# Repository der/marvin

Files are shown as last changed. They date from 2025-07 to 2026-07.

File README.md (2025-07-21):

# Marvin

Project to built a mobile, sensing, semi-intelligent robot.

## Goal capabilities

- can drive from a joystick
- can drive itself from base AI model, including explore for itself
- proximity sensing and never crashes into things
- audio input
	- directional audio to allow turn to sound?
- audio output
- vision for scene understanding and face recognition
- some emoting - know when it hears you or recognises you, when thinking or exploring
- modular system so could change to biped or add manipulators in the future

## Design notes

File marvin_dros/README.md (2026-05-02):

# Controller and sensor nodes for Marvin

Originally used ROS2 over rosbridge.

Ditched ROS2 as too unstable, and moved to simple websocket based pub/sub mechanism.

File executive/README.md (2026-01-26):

# Marvin Executive System

An intelligent rover control system that uses LLM-based agents for high-level planning and decision-making.

## Overview

This system controls a mobile rover with mecanum wheels, camera, and sensors through a two-layer architecture:

- **Executive Agent**: High-level planning and decision-making using an LLM (via pydantic-ai)
- **Cortex**: Low-level control, state monitoring, and obstacle detection

## Components

### State Models (`state.py`)
Defines shared state structures:
- `RoverState`: Low-level rover status (heading, movement, obstacles, visible objects)
- `HighLevelState`: Executive-level state (mode, goals, plans)

### Cortex (`cortex.py`)
Low-level rover control:
- Monitors sensors every 200ms
- Executes movement plans
- Stops automatically when obstacles are < 10cm away
- Uses dummy interface (replace with actual camera_server API later)

### Executive Agent (`executive.py`)
LLM-powered decision-making with tools:
- `check_object_visible`: Check if named object is in view
- `turn_to_object`: Rotate to face a visible object
- `move_direction`: Move forward/backward for a distance
- `get_current_heading`: Query current compass heading
- `get_obstacle_distance`: Check distance to nearest obstacle
- `update_goal`: Set new high-level goal

### Dialog Handler (`dialog.py`)
User interaction interface:
- Processes text commands from terminal
- Special commands: `stop`, `status`, `quit`/`exit`
- Coordinates between executive and cortex

## Setup

1. Install dependencies:
```bash
pip install -r requirements.txt
```

2. Make sure you have an LLM running with OpenAI-compatible API (e.g., llama.cpp server):
```bash
# Example: llama.cpp server on port 8080
./server -m model.gguf --port 8080
```

## Usage

Run the system:
```bash
python main.py
```

With custom LLM settings:
```bash
python main.py --model-url http://localhost:8080/v1 --model-name my-model
```

### Commands

- Type natural language instructions (e.g., "turn left", "find the teddy bear")
- `stop` - Emergency stop the rover
- `status` - Show current system state
- `quit` or `exit` - Shutdown

### Example Tasks

From the design outline:
- "there's a teddy bear to your left, go up to it"
- "turn around and tell me what objects you see"
- "go up to the waste basket"
- "can you see a book? what is it called?"
- "explore this room and find a book and a bear"

## Current Implementation Status

✅ Core framework with state management
✅ Executive agent with pydantic-ai and tool definitions
✅ Cortex with dummy rover interface
✅ Dialog handler for user interaction
✅ Asynchronous control loops

🔄 Using dummy data for:
- Rover movement (simulated)
- Object detection (random dummy objects)
- Obstacle distance (simulated)

## Future Enhancements

1. **Replace dummy interface**: Connect to actual `../pi-master/camera_server.py`
2. **Vision integration**: Add real object detection using VLM
3. **Better planning**: More sophisticated movement sequences
4. **Odometry**: Track actual distance traveled
5. **Vision-language model**: Integrate VLM for visual understanding
6. **Persistent memory**: Save and recall previous interactions

## Architecture

```
┌─────────────┐
│   User      │
│   Input     │
└──────┬──────┘
       │
┌──────▼──────────┐
│  Dialog Handler │
└──────┬──────────┘
       │
┌──────▼────────────┐      ┌─────────────┐
│ Executive Agent   │◄─────┤  LLM API    │
│  (High Level)     │      │  (OpenAI)   │
└──────┬────────────┘      └─────────────┘
       │
       │ Plans/Commands
       │
┌──────▼──────────┐       ┌──────────────┐
│     Cortex      │◄──────┤  Rover API   │
│  (Low Level)    │       │ camera_server│
└─────────────────┘       └──────────────┘
       │
       │ Motor Control
       │
┌──────▼──────────┐
│  Physical Rover │
│  Sensors/Camera │
└─────────────────┘
```

## Notes

- The system runs two async loops: cortex control and dialog handling
- State updates happen every 200ms by default (configurable)
- Obstacle detection triggers automatic stops
- The framework is designed to be extended with real hardware interfaces

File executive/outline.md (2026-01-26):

# Outline of executive and cortex structure

## Background

This will the controller for a small mobile droid interacting with a domestic environment. The physical capabilities of the droid will evolve over time. Currently it comprises:

- a mobile rover platform with mercanum wheels above to move forward/back, rotate on the spot but also slide sideways or diagonally
- a camera able to deliver video or still capture at low or HD resolution
- sensors for absolute heading and distance to obstacles in front (and at 30 degrees either side of the front)
- an onboard Raspberry Pi running a web server that can be used to obtain camera and sensor data and to send movement instructions

The web server code is in ../pi-master/camera_server.py

## Goal for this development

Build an agent layer (the "executive") that takes prompts form the user (initially typed into the terminal) and maps out a plan for what the rover should do.

Build a lower layer (the "cortex") which executes the plan but monitors if the rover is getting too close to an obstacle or if the plan is complete. In such cases it should stop the rover and ask the executive what to do next.

The LLMs used by the executive will be running locally in llama.cpp in this machine, the details of that are out of scope here.

There will be a thinking model on one localhost port and a VLM model on another port.

## Example test tasks

- there's a teddy bear to your left, go up to it
- turn around and tell me what objects you see
- go up to the waste basket
- can you see a book?
  what is it called?
- explore this room and find a book and a bear

## Initial outline

### Dialog handler

- A module that takes text input from the terminal.
- If the text is "stop" it tells the context the stop the rover.
- Otherwise it should pass the prompt the exective along with a summary of the current state so that the executive can decide whether to change the plan or simply repond to the prompt without changing the plan.
- Outputs from the executive agent should be shown back the user

### An Executive Agent

- This should use an LLM on a localhost port (with OpenAI compatible completions API).
- It should be implemented using the pydantic.ai framework
- It should take current state, event updates from the cortext and prompts from the user and either:
   - send a text response to the user without further need for tool use
   - use tool calls to help answer the question but without changing the plan
   - update the plan the cortext should be following

### A cortex module

- This should maintain a state object for the current plan and drive the rover via the camera_server web interface to execute the plan
- Check if there an obstacle closer than 10cm and if so stop the rover and inform the executive
- Provide a call that the dialog handler can invoke directly if the users says "stop"
- the cortex should update the rover state information (see below) once every 200ms

### State

The modules should coordinate via two groups of state information.

#### High level state

- rover mode (standby, acting)
- current goal as set by the user prompts
- high level plan for how to achieve this generated by the executive LLM

#### Rover state

- heading
- isMoving
- distanceToObstacle
- current camera image
- list of visible objects and their heading

### Tools to provide to the executive

- check if an object of named time is visible
- turn to the object, if is visible
- move in a direction for a distance
- a sequence of movment actions
- get the current heading
- return the distance to obstacle in front

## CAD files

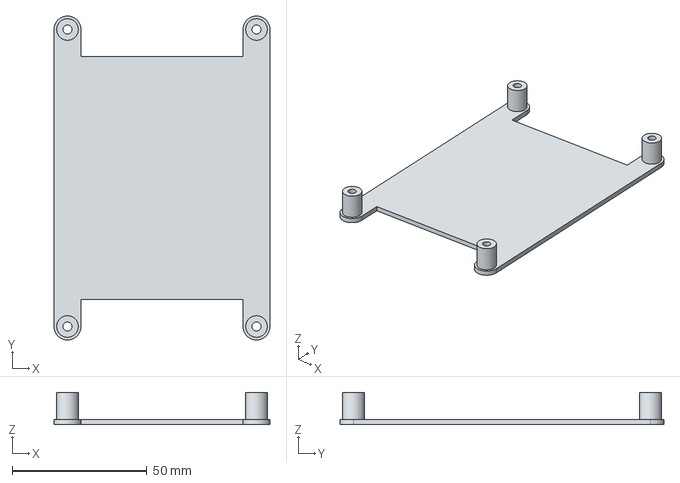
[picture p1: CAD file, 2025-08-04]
motor-base/cad/Underplate.step
80.0 x 120.0 x 12.0 mm

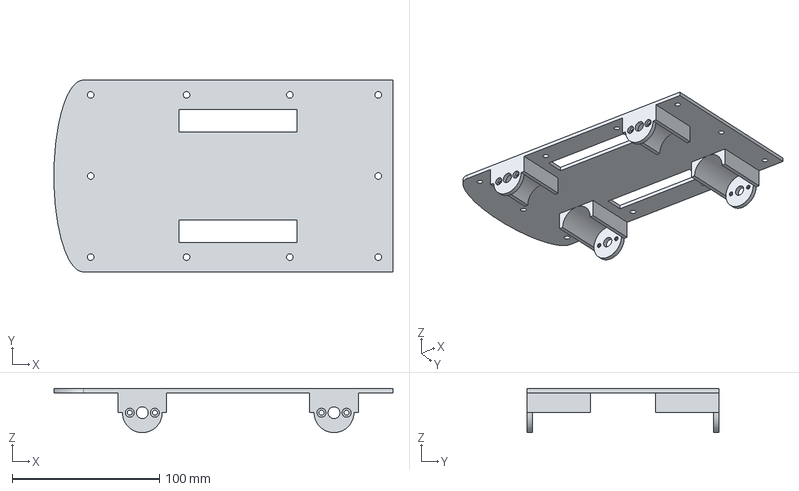
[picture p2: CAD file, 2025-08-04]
motor-base/cad/Base.step
229.9 x 130.0 x 30.0 mm

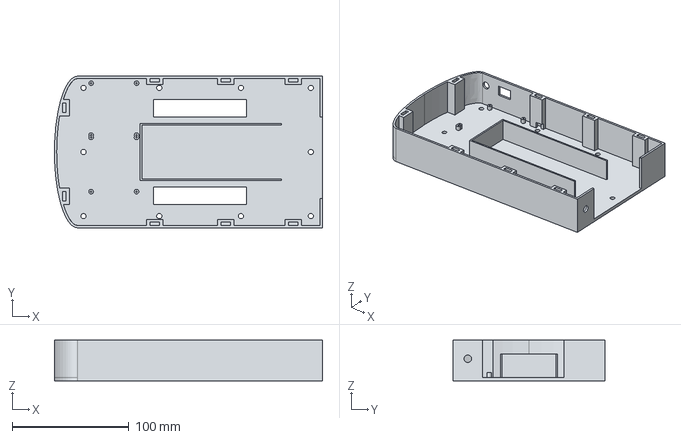
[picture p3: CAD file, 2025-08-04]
motor-base/cad/PowerLayer.step
229.9 x 130.0 x 35.0 mm

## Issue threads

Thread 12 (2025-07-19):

Design and print prototyping base

der, 2025-07-19:
- supports for fixing to mobile base
- pi fixing
- camera fixing
- space for front lidar or us
- elevated platform for full lidar
- hole for power cable
-

Closed 2025-10-04.

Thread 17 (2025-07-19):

Test wifi stability with motion

der, 2025-07-19:

der, 2025-08-22:
Not great even with second dongle acting as an AP.

Getting dropouts, and long drop outs of round corner from controller, might be partly controller wifi pickup but.

der, 2025-08-22:
Dropped use of AP so pi can use either builtin or dongle wifi to reach house network, noticeably more stable.

Closed 2025-08-22.

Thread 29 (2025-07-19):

Audio output on pi

der, 2025-07-19:

der, 2025-08-24:
USB audio speaker works but a little quiet out of the box.

To discover the device use `pw-cli ls Node`, fine the node that mentions output or stereo and get its id. For Marvin it seems to be 87.
```
	id 87, type PipeWire:Interface:Node/3
 		object.serial = "88"
 		object.path = "alsa:acp:UACDemoV10:1:playback"
 		factory.id = "19"
 		client.id = "36"
 		device.id = "68"
 		priority.session = "1009"
 		priority.driver = "1009"
 		node.description = "UACDemoV1.0 Analog Stereo"
 		node.name = "alsa_output.usb-Jieli_Technology_UACDemoV1.0_4150344133363815-00.analog-stereo"
 		node.nick = "UACDemoV1.0"
 		media.class = "Audio/Sink"
```
Then can set the volume with e.g.:
```
pw-cli s 87 Props '{channelVolumes:[2.0,2.0]}'
```
Tested this by apt installing espeak and using that to get test speech output.

Closed 2025-08-24.

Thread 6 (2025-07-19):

Design and print base plate for motors

der, 2025-07-19:
- motor brackets
- holes for motor cables
- circuit board fixing holes
- fixing hole for battery compartment
- slots for droid shell

der, 2025-08-03:
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

Closed 2025-08-03.

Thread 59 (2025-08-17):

Make BLE to motor board more reliable

der, 2025-08-17:
Sometimes says "disconnected" when try to start up, also complains about disconnect not waited for.

Set up an restart thread which tries to reconnect if lost and cleans up better.

Closed 2025-10-04.

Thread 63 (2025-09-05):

Find the bear

der, 2025-09-05:
Command to locate a teddy bear in the surroundings.

Initially just rotate on the spot and use yolo open world to detect bear. Adjust angle till bear is centred.

Option describe the scene.

der, 2025-09-27:
## Overall goal
Detect Teddy Bear, orient on it and get closer.
## Object detection
Used `yoloe-11s-seg` compiled to NCNN format which gives 3-4 frames/second on Pi.

The 2 x 10,0000uF decoupling is enough to keep that stable.

Give a list of a dozen or so household objects as the classes before compiling to NCNN.
```
def prep_ncnn():
    model = YOLOE(MODEL_SRC)
    model.set_classes(classes, model.get_text_pe(classes))
    model.export(format="ncnn")
```

In use pick the class number for the target (1 for _Teddy Bear_) and if get any detection is a bear. Offset gives orientation and width gives an indication of how close.

## Algorithm
Turn until spotted.
Use offset to decide on angle to rotate, repeat until as centred as can get it.
If width too small approach in 20cm bursts

Basically works.

## Lessons

- basic object detection on raw Pi is surprisingly good and fast enough.
- detection very poor while moving so had to pause after move to recheck.
- thresholds for angle to correct to and move distances are sensitive, in particular if make angle threshold too small it tries to rotate by 0 and gets stuck in a loop
- voice messages at key stages makes the whole thing compelling but speaker is not load enough and the `flite` voice, while nicely robotic, is a little unclear

der, 2025-10-04:
See: https://www.dropbox.com/scl/fi/ngcjpv9aepke4bw3yzaap/20250926_221054.mp4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

Closed 2025-10-04.

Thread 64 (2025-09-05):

Move/rotate distance

der, 2025-09-05:
Extend motor controller to set number of pulses to move by.
Expose as optional limit.
Check limit needed for forward 10 cm and for rotate 10 deg

Add this to camera server

Closed 2025-09-07.

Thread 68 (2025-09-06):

Diagnose pi-5 crashing

der, 2025-09-06:
When trying to run yolo inference the pi shutsdown after a few frames.

Memory? Thermal overload? Power stability@

Can't see any persistent system logs to diagnose with.

der, 2025-09-16:
With original converter and 2 x 10,000uF ballast direct on pi-5 getting stable loop using yolo-v8s-world in a loop at just over 3 frames a second. Good enough to work with, eventually will offload higher levels of image processing to a brain base station anyway.

Closed 2025-10-04.

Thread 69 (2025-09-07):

Wait for movement completion

der, 2025-09-07:
After a move request with distance cut off would like some way to signal that the movement is done.

Possibly a speed endpoint that can check when stops, or a synchronous mode so the request doesn't return until comleted.

Closed 2025-09-27.

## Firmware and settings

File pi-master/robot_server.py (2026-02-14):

#!/usr/bin/env python3
from picamera2 import Picamera2
from libcamera import Transform, controls
from copy import copy
import cv2
import asyncio
import time
import sys
import threading
from typing import Iterator
from fastapi import FastAPI, Response
from fastapi.responses import HTMLResponse, StreamingResponse
import uvicorn
from contextlib import asynccontextmanager
import zlib
from motor_control import MotorController
from dist_heading_sensor import DistanceHeadingMonitor
from actions import rotate_to_heading, move_along_heading
from eyes import Eyes
from st3215 import ST3215
import os

# Configuration
HOST = "0.0.0.0"  # Allow access from any device on the network
PORT = 80
JPEG_QUALITY = 70  # 0-100, higher is better quality but larger size

# Global variable for camera and frame handling
camera = None
frame_lock = threading.Lock()
latest_lores = None
latest_frame = None
stream_active = True


def initialize_camera():
    """Initialize the camera."""
    global camera
    try:
        camera = Picamera2()
        config = camera.create_still_configuration(
            buffer_count=2, transform=Transform(vflip=True, hflip=True)
        )
        config["main"] = {"format": "RGB888", "size": (1024, 768), "preserve_ar": True}
        config["lores"] = {"format": "RGB888", "size": (320, 240), "preserve_ar": True}
        camera.set_controls({"AfMode": controls.AfModeEnum.Continuous})
        camera.configure(config)

        # To do, set up sizes and lores
        camera.start()
        time.sleep(1)
        print("Camera initialized successfully.")
        return True
    except Exception as e:
        print(f"Error initializing camera: {e}")
        return False


def capture_frames():
    """Continuously capture frames from the camera."""
    global latest_lores, latest_frame, stream_active

    while stream_active:
        (main, lores), metadata = camera.capture_arrays(["main", "lores"])
        if lores is not None:
            # print(f"Captured frame: {lores.shape}")
            with frame_lock:
                latest_frame = copy(main)
                latest_lores = copy(lores)


@asynccontextmanager
async def lifespan(app: FastAPI):
    await startup()
    yield
    # Clean up the ML models and release the resources
    await shutdown()


app = FastAPI(title="Pi Rover Camera Server", lifespan=lifespan)

# Camera block

def generate_frames() -> Iterator[bytes]:
    """Generate frames for the multipart response."""
    while True:
        # Wait until a frame is available
        if latest_lores is None:
            time.sleep(0.01)
            continue

        # Get the current frame
        with frame_lock:
            ret, jpeg = cv2.imencode(
                ".jpg", latest_lores, [cv2.IMWRITE_JPEG_QUALITY, JPEG_QUALITY]
            )
            if ret:
                # Convert the frame to bytes
                frame_data = jpeg.tobytes()

        # Yield the frame in the format expected by multipart responses
        yield (b"--frame\r\nContent-Type: image/jpeg\r\n\r\n" + frame_data + b"\r\n")


@app.get("/stream")
async def stream():
    """Stream the camera feed as multipart/x-mixed-replace content."""
    return StreamingResponse(
        generate_frames(), media_type="multipart/x-mixed-replace; boundary=frame"
    )


@app.get("/still")
async def still():
    """Single high-res image."""
    return await response_for(latest_frame)


@app.get("/still-lores")
async def still_lores():
    """Single log-res image."""
    return await response_for(latest_lores)


@app.get("/still-565")
async def still_565():
    frame = latest_lores
    if frame is None:
        return Response(content="No image available", media_type="text/plain")

    with frame_lock:
        # Convert the frame to RGB565 format
        rgb565_frame = frame.astype("uint16")
        # Implicit RGB to BGR via swapping suffixes instead of using cvtColor
        rgb565_frame = (
            ((rgb565_frame[:, :, 2] >> 3) << 11)
            | ((rgb565_frame[:, :, 1] >> 2) << 5)
            | (rgb565_frame[:, :, 0] >> 3)
        )
        # Swap the bytes to big-endian format
        rgb565_bytes = rgb565_frame.byteswap().tobytes()
        # Compress the RGB565 data using zlib
        compressed_data = zlib.compress(rgb565_bytes)
    return Response(content=compressed_data, media_type="application/octet-stream")


async def response_for(frame):
    if frame is None:
        return Response(content="No image available", media_type="text/plain")

    with frame_lock:
        ret, jpeg = cv2.imencode(
            ".jpg", frame, [cv2.IMWRITE_JPEG_QUALITY, JPEG_QUALITY]
        )
        if ret:
            return Response(content=jpeg.tobytes(), media_type="image/jpeg")
        else:
            return Response(content="Failed to encode image", media_type="text/plain")


@app.get("/", response_class=HTMLResponse)
async def index():
    """Serve a simple HTML page with the stream embedded."""
    html_content = """
    <html>
    <head>
        <title>Pi Rover Camera Stream</title>
        <style>
            body { 
                font-family: Arial, sans-serif; 
                text-align: center;
                margin: 0;
                padding: 20px;
                background-color: #f5f5f5;
            }
            .container {
                max-width: 800px;
                margin: 0 auto;
                background-color: white;
                border-radius: 10px;
                padding: 20px;
                box-shadow: 0 4px 6px rgba(0, 0, 0, 0.1);
            }
            h1 {
                color: #333;
            }
            .stream-container {
                margin-top: 20px;
                overflow: hidden;
                border-radius: 8px;
                box-shadow: 0 2px 4px rgba(0, 0, 0, 0.1);
            }
            img {
                max-width: 100%;
                display: block;
            }
        </style>
    </head>
    <body>
        <div class="container">
            <h1>Pi Rover Camera Stream</h1>
            <div class="stream-container">
                <img src="/stream" alt="Pi Rover Camera Stream" />
            </div>
        </div>
    </body>
    </html>
    """
    return HTMLResponse(content=html_content)

# Motor controller block

motor = MotorController()

@app.post("/set-motor")
async def set_motor(s: int, dir: str, dist: int = None, sync: bool = False):
    """
    Set the speed, direction and optional distance of the motor
    Example: POST /set-motor?s=50&dir=f&dist=5
    """
    try:
        if motor.is_connected:
            command = "s" if dir == "s" else f"{s}{dir}"
            if dist is not None:
                command += f"{dist}"
            else:
                command += 99
            motor.queue.append(command)
            if sync:
                await asyncio.sleep(0.05)
                while await motor.is_moving():
                    await asyncio.sleep(0.1)
            return {
                "status": "success",
                "message": f"Motor set to dir={dir}, speed={s}, dist={dist}",
            }
        else:
            return {"status": "error", "message": "Motor base BLE connection not ready"}
    except Exception as e:
        return {"status": "error", "message": str(e)}


@app.get("/is-moving")
async def is_moving():
    """Check if the motor is currently moving."""
    try:
        if motor.is_connected:
            moving = await motor.is_moving()
            return {"status": "success", "moving": moving}
        else:
            return {"status": "error", "message": "Motor base BLE connection not ready"}
    except Exception as e:
        return {"status": "error", "message": str(e)}

# Sensor block

sensor = DistanceHeadingMonitor()

@app.get("/sensor-status")
async def sensor_status():
    """Get the current sensor status."""
    try:
        if sensor.is_connected:
            status = {
                "heading": sensor.heading,
                "pitch": sensor.pitch,
                "distance" : sensor.dist,
            }
            return {"status": "success", "sensor_status": status}
        else:
            return {"status": "error", "message": "Sensor connection not ready"}
    except Exception as e:
        return {"status": "error", "message": str(e)}

@app.post("/turn-to-heading")
async def turn_to_heading(heading: int, sync: bool = False):
    if heading < 0 or heading > 255:
        return {"status": "error", "message": "Heading must be between 0 and 255"}
    if not sensor.is_connected:
        return {"status": "error", "message": "Sensor connection not ready"}
    if not motor.is_connected:
        return {"status": "error", "message": "Motor base BLE connection not ready"}
    task = asyncio.create_task(rotate_to_heading(heading, sensor, motor))
    if sync:
        await task
        return {"status": "success", "message": f"Turning to heading {heading}"}
    return {"status": "turning"}

@app.post("/move-along-heading")
async def move_heading(dist: int, heading: int, sync: bool = False):
    if not sensor.is_connected:
        return {"status": "error", "message": "Sensor connection not ready"}
    if not motor.is_connected:
        return {"status": "error", "message": "Motor base BLE connection not ready"}
    task = asyncio.create_task(move_along_heading(dist, heading, sensor, motor))
    if sync:
        await task
        return {"status": "success", "message": f"Moving along heading {heading} for {dist} units"}
    return {"status": "moving"}

# Eyes controller block

eyes = Eyes()

@app.post("/set-eyes")
async def set_eyes(awake: bool = True, wide: bool = False, x: int = 0):
    """
    Set the eyes state and position.
    awake: true/false default true
    wide: true/false default false
    x: offset of eyes between -100 and 100
    """
    try:
        eyes.set_awake(awake)
        if (awake):
            eyes.set_wide_eyes(wide)
            eyes.set_eyes_at(x)
        return {"status": "success", "message": f"Eyes set to awake={awake}, wide={wide}, x={x}"}
    except Exception as e:
        return {"status": "error", "message": str(e)}

# Neck block

servo = ST3215('/dev/ttyACM0')

TILT_RANGE = 250
PAN_RANGE = 750

@app.post("/set-neck")
async def set_neck(tilt: int, pan: int, speed: int =2000):
    """
    Set the neck tilt and pan angles.
    tilt: range -100 to 100
    pan: range -100 to 100
    speed: movement speed (default 2000)
    """
    try:
        if tilt < -100 or tilt > 100 or pan < -100 or pan > 100:
            return {"status": "error", "message": "Tilt and pan must be between -100 and 100"}
        tilt = int(tilt * TILT_RANGE / 100) + 2048
        pan = int(pan * PAN_RANGE / 100) + 2048
        servo.MoveTo(0, tilt, speed=speed, acc=50, wait=False)
        servo.MoveTo(1, pan, speed=speed, acc=50, wait=False)
        return {"status": "success", "message": f"Neck set to tilt={tilt}, pan={pan}"}
    except Exception as e:
        return {"status": "error", "message": str(e)}

@app.get("/get-neck")
async def get_neck():
    """
    Get the current neck tilt and pan angles.
    """
    try:
        tilt_pos = servo.ReadPosition(0)
        pan_pos = servo.ReadPosition(1)
        tilt = int((tilt_pos - 2048) * 100 / TILT_RANGE)
        pan = int((pan_pos - 2048) * 100 / PAN_RANGE)
        return {"status": "success", "tilt": tilt, "pan": pan}
    except Exception as e:
        return {"status": "error", "message": str(e)}

@app.post("/shutdown")
async def shutdown_endpoint():
    """Shutdown the robot server."""
    await shutdown()
    # Stop the server
    os.system("sudo shutdown now")

async def startup():
    """Initialize camera and start frame capture thread on startup."""
    if not initialize_camera():
        print("Failed to initialize camera. The stream will not work.")
        return
    
    # Start the frame capture thread
    capture_thread = threading.Thread(target=capture_frames)
    capture_thread.daemon = True
    capture_thread.start()
    print("Camera capture thread started.")
    # Start BLE connection listener
    lock = asyncio.Lock()
    print("Starting BLE connection to motor base in background")
    asyncio.create_task(motor.run(lock))
    # Start sensor listener
    print("Starting sensor listener")
    asyncio.create_task(sensor.run(lock))
    # Eyes controller
    asyncio.create_task(eyes.run())
    eyes.set_awake(True)


async def shutdown():
    """Release camera resources on shutdown."""
    global stream_active
    stream_active = False
    if camera is not None:
        camera.stop()
        print("Camera stopped.")
    if motor.is_connected:
        motor.shutdown()


def main():
    """Main function to start the FastAPI server with Uvicorn."""
    try:
        print(f"Starting server at http://{HOST}:{PORT}")
        print("Press Ctrl+C to stop the server")
        uvicorn.run(app, host=HOST, port=PORT)
    except KeyboardInterrupt:
        print("\nShutting down...")


if __name__ == "__main__":
    main()

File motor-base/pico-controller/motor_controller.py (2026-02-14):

from machine import Pin, PWM
from time import sleep, ticks_us, ticks_diff
import micropython
import uasyncio as asyncio

# Needed if we have hard IRQs for debugging
micropython.alloc_emergency_exception_buf(100)
MAX_DUTY = 65535
MAX_SPEED = 160

class Motor(object):
    def __init__(self, pwm_pin, dir_pin, pulse_pin, average_over=1):
        self.average_over = average_over
        self.pwm = PWM(pwm_pin, freq=5000, duty_u16=MAX_DUTY)
        self.dir_pin = dir_pin
        self.pulse_pin = pulse_pin
        self.speed = 0
        self.pulse_count=0
        self.pulse_total=0
        self.pulse_average=0
        self.pulse_last=0
        self.countdown=None
        self.counted_down=False
        pulse_pin.irq(self.pulse, Pin.IRQ_RISING | Pin.IRQ_FALLING, hard=True)

    def pulse(self, arg):
        if self.pulse_pin.value() == 1:
            # Start of pulse
            self.pulse_last = ticks_us()
        else:
            self.pulse_total += ticks_diff(ticks_us(), self.pulse_last)
            self.pulse_count += 1
            if self.countdown is not None:
                self.countdown -= 1
                if self.countdown == 0:
                    self.set_speed(0)
                    self.counted_down = True
                    self.countdown = None
            if self.pulse_count >= self.average_over:
                self.pulse_average = self.pulse_total // self.average_over
                self.pulse_count = 0
                self.pulse_total = 0

    def set_speed(self, speed):
        """
            Set speed in %age of full speed (around 150rpm)
        """
        if speed > 100:
            speed = 100
        elif speed < -100:
            speed = -100
        self.speed = speed
        self.pwm.duty_u16(((100 - abs(speed)) * MAX_DUTY)//100)
        self.dir_pin.value(1 if speed > 0 else 0)
        self.pulse_average = 0

    def set_countdown(self, count):
        """
           Set a distance limit in (approx) cmd based on pulse counting
           Estmate about 14 pulses per cm
        """
        if count is not None:
            self.countdown = 14 * count
            self.counted_down = False
        else:
            self.countdown = None

    def get_speed(self):
        if self.pulse_average == 0:
            return 0
        # 45:1 gear, 6 pulses per motor rev, not sure I understand the factor of 2  
        speed = 60*1000000/(45*6*2*self.pulse_average)
        speed = 100 * speed / MAX_SPEED  # Convert to percentage of max speed
        return speed if speed < 100 else 100

def limit_speed(speed: float) -> int:
    """
    Limit the speed to the range 0 to 100.
    """
    if speed > 100:
        return 100
    elif speed < 0:
        return 0
    return int(speed)

class MotorPID:
    def __init__(self, motor: Motor, kp:float = 0.3, ki:float = 0.1, kd:float = 0.05):
        self.motor = motor
        self.kp = kp
        self.ki = ki
        self.kd = kd
        self.setpoint = 0
        self.reverse = False
        self.last_setting = 0
        self.last_value = 0
        self.integral = 0

    def set_speed(self, speed: int):
        self.setpoint = abs(speed)
        self.reverse = speed < 0
        
    def get_speed(self):
        return self.motor.speed
    
    def update(self):
        if self.motor.counted_down:
            self.setpoint = 0
            self.counted_down = False
        if self.setpoint == 0:
            self.motor.set_speed(0)
            return
        current_value = self.motor.get_speed()
        error = self.setpoint - current_value
        self.integral = limit_speed(self.integral + error)
        # Use derivative kick trick: http://brettbeauregard.com/blog/2011/04/improving-the-beginners-pid-derivative-kick/
        derivative = -(current_value - self.last_value)
        delta = (self.kp * error) + (self.ki * self.integral) + (self.kd * derivative)
        output = limit_speed(self.last_setting + delta)
        self.last_setting = output
        self.last_value = current_value
        speed = -output if self.reverse else output
        #print(f"Current: {current_value}, Error: {error}, Delta: {delta}, Output: {output}, Speed: {speed}")
        self.motor.set_speed(speed)

def init_motor(start:int):
    pwm = Pin(start, Pin.OUT)
    dir = Pin(start+1, Pin.OUT)
    pulse = Pin(start+2, Pin.IN, Pin.PULL_UP)
    motor = Motor(pwm, dir, pulse, 2)
    return MotorPID(motor)


MOTOR_DECODE = {
     "f" : [ 1, 1, 1, 1],
     "b" : [-1,-1,-1,-1],
    "sr" : [ 1,-1,-1, 1],
    "sl" : [-1, 1, 1,-1],
    "dr" : [ 1, 0, 0, 1],
    "Dl" : [-1, 0, 0,-1],
    "dl" : [ 0, 1, 1, 0],
    "Dr" : [ 0,-1,-1, 0],
    "tr" : [ 1, 1, 0, 0],
    "tl" : [ 0, 0, 1, 1],
    "Tr" : [ 0, 0,-1,-1],
    "Tl" : [-1,-1, 0, 0],
    "rr" : [ 1, 1,-1,-1],
    "rl" : [-1,-1, 1, 1],
     "s" : [ 0, 0, 0, 0],
}

class MotorControl:
    """
        Class to control multiple motors with PID.
        Motors are initialized  on GPIO pin groups 10+11+12, 13+14+15, 16+17+18 and 19+20+21.
        Each group has 3 pins: PWM, Direction and Pulse.

        The update loop runs every 50ms to update the motor speeds and needs to be run in an asyncio event loop.
    """
  
    def __init__(self):
        self.motors = [init_motor(i) for i in range(10, 22, 3)]

    def get_motors(self):
        return self.motors
    
    def pid_update(self):
        for motor_pid in self.motors:
            motor_pid.update()

    def set_speed(self, speeds: list[int]):
        """
        Set the speed of each motor in the list.
        Speeds should be a list of integers corresponding to each motor.
        """
        for i, speed in enumerate(speeds):
            if i < len(self.motors):
                # print(f"setting speed of {i} to {speed if i > 1 else -speed}")
                # reverse left hand side motors (because mounted other way!)
                self.motors[i].set_speed(speed if i > 1 else -speed)

    def set_all_speeds(self, speed: int):
        """
        Set the speed of all motors to the same value.
        """
        self.set_speed([speed]*4)
        
    def is_stopped(self):
        speed = 0
        for m in self.motors:
            speed = max(speed, abs(m.get_speed()))
        return speed == 0
        
    def set_motion(self, speed: int, dir: str, count: int|None = None):
        pattern = MOTOR_DECODE.get(dir) or [0,0,0,0]
        self.set_speed([x*speed for x in pattern])
        print("setting speed:", [x*speed for x in pattern])
        self.set_countdown(count)

    def set_countdown(self, count: int):
        """
        Limit the motion to (appox) the given number of cm
        """
        for motor in self.motors:
            motor.motor.set_countdown(count)

    async def pid_update_loop(self):
        while True:
            self.pid_update()
            await asyncio.sleep(0.05)

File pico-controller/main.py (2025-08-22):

# Initialise hardware and framebuf before importing modules.
from color_setup import ssd,sd,touch  # Create a display instance
from gui.core.nanogui import refresh
refresh(ssd, True)  # Initialise and clear display.

# Now import other modules
from gui.widgets.label import Label
from gui.widgets.textbox import Textbox
from gui.core.writer import CWriter
import utime
import asyncio
import deflate
import network
from urllib.urequest import urlopen
from joystick_controller import JoystickController
from machine import ADC, Pin

# Configuration
ROVER="http://marvin.local:8080/"
NETWORK="amberdown"
PASSWORD="candleandthestar"

# Font for CWriter
import gui.fonts.freesans20 as font
from gui.core.colors import *

class Button:
    """A class representing a button on the display."""
    BUTTON_HEIGHT = 20
    BUTTON_WIDTH = 80

    def __init__(self, wri, text, row, col, selected=False):
        self.row = row
        self.col = col
        self.text = text
        self.selected = selected
        self.label = Label(wri, row, col, text, bdcolor=GREEN if selected else RED)

    def check_touch(self, touch):
        """Checks if the button is touched."""
        row, col = touch
        if (col > self.col and col < self.col + self.BUTTON_WIDTH and 
                row > self.row and row < self.row + self.BUTTON_HEIGHT):
            return True
        return False
    
    def set_selected(self, selected):
        """Sets the button as selected or not."""
        self.selected = selected
        self.label.value(bdcolor=GREEN if selected else RED)

class ButtonSet:
    BUTTON_LEFT = 230
    BUTTON_SPACING = 35

    """A class representing a set of buttons on the display."""
    def __init__(self, wri, labels):
        self.wri = wri
        self.offset = self.BUTTON_SPACING
        self.buttons = []
        for label in labels:
            self.add_button(label)
        self.selected_button = None
    
    def select_button(self, label):
        """Selects a button by its label."""
        for button in self.buttons:
            if button.text == label:
                button.set_selected(True)
                self.selected_button = button
            else:
                button.set_selected(False)

    def add_button(self, label):
        """Adds a button to the set."""
        self.buttons.append(Button(self.wri, label, self.offset, self.BUTTON_LEFT))
        self.offset += self.BUTTON_SPACING

    def check_touch(self, touch):
        """Checks if any button in the set is touched."""
        for button in self.buttons:
            if button.check_touch(touch) and button.text != self.selected_button.text:
                # print(f"Button {button.text} touched")
                self.selected_button.set_selected(False)
                button.set_selected(True)
                self.selected_button = button
                return button.text
        return None

class Screen:
    """A class representing a screen on the display."""
    def __init__(self, wri, name):
        self.wri = wri
        self.name = name

    async def install(self):
        """Installs the screen with any common widgets"""
        pass
    
    async def await_data(self):
        """Awaits for incoming data, that will be displayed."""
        pass

    async def update_display(self):
        """Updates the display with new data."""
        pass

    async def handle_touch(self, touch):
        """Handles touch events."""
        pass

class ImageScreen(Screen):
    """A class representing an image screen."""
    def __init__(self, wri, name, file):
        super().__init__(wri, name)
        self.file = file

    async def await_data(self):
        await asyncio.sleep(0.05)  # Simulate waiting for data

    async def update_display(self):
        """Updates the display with the image."""
        # print(f"Updating display with image {self.file}")
        with open(self.file, "rb") as f:
            f.readinto(ssd.mvb)
        refresh(ssd)  # Display the image

class WebImageScreen(Screen):
    def __init__(self, wri, name, url):
        super().__init__(wri, name)
        self.url = url

    async def await_data(self):
        # Dummy, sleep briefly just to allow touch check
        await asyncio.sleep(0.01)

    async def update_display(self):
        """Updates the display with the image."""
        try:
            # print("Trying to open", self.url)
            s = urlopen(self.url)
            with deflate.DeflateIO(s, deflate.ZLIB) as d:
                d.readinto(ssd.mvb)
            s.close()
            refresh(ssd)  # Display the image
        except Exception as e:
            print("problem fetching image", e)
            Label(self.wri, 180, 10, "Problem fetching image", bgcolor=RED)
            
    async def install(self):
        print("Camera activated")
    
class DummyScreen(Screen):
    """A class representing a dummy screen."""
    def __init__(self, wri, text):
        super().__init__(wri, text)
        self.text = text

    async def await_data(self):
        await asyncio.sleep(0.1)
        
    async def update_display(self):
        await asyncio.sleep(0.1)

    async def install(self):
        Label(self.wri, 100, 100, self.text, bgcolor=BLUE)

battery_conversion_factor = 3 * 3.3 / 65535
full_battery = 4.2
empty_battery = 2.8  

class BatteryScreen(Screen):
    """Test screen for measuring battery level"""
    def __init__(self, wri, name):
        super().__init__(wri, name)
        self.vsys = ADC(Pin(29))
        self.text = "No reading"
    
    def measure_battery(self):
        voltage = self.vsys.read_u16() * battery_conversion_factor
        print("Voltage", voltage)
        percentage = 100 * ((voltage - empty_battery) / (full_battery - empty_battery))
        if percentage > 100:
            percentage = 100.00
        return percentage, voltage
    
    async def await_data(self):
        await asyncio.sleep(0.1)
        
    async def update_display(self):
        percentage, voltage = self.measure_battery()
        self.text = f"{voltage:.2f}V {percentage:.2f}%"
        Label(self.wri, 100, 100, self.text, bgcolor=BLUE)

    async def install(self):
        Label(self.wri, 100, 100, self.text, bgcolor=BLUE)
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

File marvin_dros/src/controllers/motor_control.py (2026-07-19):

# Support for controlling the motor base over BLE
import sys
from bleak import BleakClient, BleakScanner
from bleak.backends.characteristic import BleakGATTCharacteristic
from bleak.backends.device import BLEDevice
from bleak.backends.scanner import AdvertisementData
import asyncio
from collections import deque
import contextlib

UART_SERVICE_UUID = "6E400001-B5A3-F393-E0A9-E50E24DCCA9E"
UART_RX_CHAR_UUID = "6E400002-B5A3-F393-E0A9-E50E24DCCA9E"
UART_TX_CHAR_UUID = "6E400003-B5A3-F393-E0A9-E50E24DCCA9E"

class MotorController:
    """
        Drive motor base over BLE.
        Send command strings in form "[s]op[d]" where s, if present is speed between 0 and 100,
        d, if present, is a distance to travel in (approx) cm
        The commands are:
            - x           - exit controller and close bluetooth
            - f b sr sl   - forward/back/slide right/slide left
            - dr dl Dr Dl - diagonal right/left forward/back
            - tr tl Tr Tl - turn right/left turn back right/left
            - rr rl       - rotate right or left
            - s           - stop
            - ?           - status request, returns 1 if moving, 0 if stopped
    """
    def __init__(self):
        # Short length queue of commands to send
        self.queue = deque([], 4)
        self.is_connected = False
        
    async def run(self, lock):
        # possible future auto-reconnect loop here
        await self.connect(lock)

    def handle_disconnect(self, _: BleakClient):
        print(f"Device {self.device} disconnected")
        self.client = None
        self.is_connected = False

    async def connect(self, lock):
        async with contextlib.AsyncExitStack() as stack:
            async with lock:
                print('Scanning for devices...')
                self.device = await BleakScanner.find_device_by_name('rover', 36000.0)
                if (self.device is None):
                    print('Device not found')
                    return  

                print(f'Connecting to {self.device.name}')
                client = await stack.enter_async_context(BleakClient(self.device, disconnected_callback=self.handle_disconnect))
                print('Connected to rover')
                self.is_connected = True
                self.client = client
                rover = client.services.get_service(UART_SERVICE_UUID)
                self.rx = rover.get_characteristic(UART_RX_CHAR_UUID)
                self.tx = rover.get_characteristic(UART_TX_CHAR_UUID)
            try:
                while self.is_connected:
                    # Check if there's a command in the queue without blocking
                    try:
                        command = self.queue.pop()
                        if command == 'x':
                            print('Quit requested')
                            self.client = None
                            self.is_connected = False
                            await client.disconnect()
                            return
                        print(f"Sending {command}")
                        await client.write_gatt_char(self.rx, command.encode(), response=False)
                    except IndexError:
                        # Give control back to the event loop to allow other tasks to run
                        await asyncio.sleep(0.01)
            except Exception as e:
                print(e)

    async def is_moving(self):
        if self.is_connected and self.client is not None:
            await self.client.write_gatt_char(self.rx, b'?', response=True)
            response = await self.client.read_gatt_char(self.tx)
            return bool(response is not None and response.decode().strip() == '1')

    def send(self, speed: int, dir: str, dist: int | None = None):
        if dist is not None:
            self.queue.append(f"{speed}{dir}{dist}")
        else:
            self.queue.append(f"{speed}{dir}")

    def stop(self):
        self.queue.append("0s")

    def shutdown(self):
        self.queue.append("s")
        self.queue.append("x")

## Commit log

2025-07-21 Basic motor access
    Addresses #1
2025-07-21 Basic PID on single motor
    Addresses #2
2025-07-21 Packaged motor controller
    Supports four motors on pico without apparent problems
    Closes #2
    Closes #3
    [main.py, motor_controller.py]
2025-08-02 Base level motor board config
    - moved motors to match new GPIO layout
    - battery voltage monitor and state LED
2025-08-04 CAD files for base
    [Base.step, Power layer.step, underplate.step]
2025-08-04 Tidy cad area
    [Base.step, PowerLayer.step, Underplate.step]
2025-08-05 Basic motor controller running
    - battery monitor task which stops motors as fail safe
    - motor controller with Mecanum control options
    - BLE uart called rover which accepts 1-2 char commands (50% speed)
    [BLEUart.py, battery_monitor.py, main_full.py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]
2025-08-10 Test ble to motor
2025-08-10 Draft pi camera server
2025-09-07 Try distance cut off
2025-09-20 Switch to yolo8
2025-09-20 Adding motor status
2025-10-05 Xiao code for distance/heading sensors
2025-10-05 Draft client for distance/heading sensors
2025-10-05 Run sensor test
2025-10-05 fix test case
2025-10-05 Compass calibration
2025-10-05 Unpack sensor data
2025-10-05 Fix calibration save
2025-10-11 Test access to sensor
2025-10-11 Attempted fix for BLE client fighting
    [dist_heading_sensor.py, motor_control.py]
2025-10-11 Revert failed attempts at lock use
    [camera_server.py, dist_heading_sensor.py, motor_control.py]
2025-10-12 Fixed multi BLE connection issues
    [camera_server.py, dist_heading_sensor.py, motor_control.py]
2025-10-12 Reinstance missing camera init
    [camera_server.py]
2025-10-13 Find bear with heading and lidar feedback
2025-11-17 Fix issue with chained actions
2026-03-07 Wrap tts in a thread
2026-04-19 Switch to interrupt event
2026-05-03 Test audio capture over web socket
2026-05-04 Reinstate interrupt message
2026-05-09 Clean up eye controls, robust audio device
2026-05-16 Motor controller wiring
2026-05-16 Stop to stop motor
2026-05-16 More motor debug
2026-05-24 Camera test
2026-05-25 Draft camera server
2026-05-25 Earlier draft camera server
2026-05-25 Fix camera RPC
2026-06-01 Suppress motor for head only dev
2026-07-12 eyes, neck, motor and vad running
2026-07-25 Wire up distance sensor
2026-07-25 Added distance sensor
2026-08-22 Add motor start/stop events
2026-08-29 Reduce noise from neck not powered
    [neck.py]
2026-08-29 Switch to usb speaker
